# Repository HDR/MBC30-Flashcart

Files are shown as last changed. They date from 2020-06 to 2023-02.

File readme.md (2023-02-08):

## Make sure you read the license, if you see anyone selling these, please send me a message.

MBC30 Flashcart inspired by retroreboot's MBC3 cartridge.

## Ordering

**OSHPark:** 

[Regular Version](https://oshpark.com/shared_projects/xqcPwiVB)

[Crystal Clear Version](https://oshpark.com/shared_projects/qh5Q5MuF)

Make sure to select the "2 oz copper, 0.8mm thickness" option before checkout

**JLCPCB:**

Upload gerbers(.zip files) to [JLCPCB](http://jlcpcb.com)

Make sure you order with the following settings:

PCB Thickness: 0.8

PCB Color: Any

Surface Finish: ENIG-RoHS

Gold Fingers: Yes (45° chamfered border)

Castellated Holes: No

**PCBWay:**

[Regular Version](https://www.pcbway.com/project/shareproject/MBC30_Flashcart___4MB___FRAM___RTC___Suicune_Edition_1.html)

[Crystal Clear Version](https://www.pcbway.com/project/shareproject/MBC30_Flashcart___4MB___FRAM___RTC___Crystal_Clear_Edition_1.html)

[Coral Version](https://www.pcbway.com/project/shareproject/MBC30_Flashcart_4MB_FRAM_RTC_Coral_Edition_2b0fe0be.html)

## BOM

| Reference | Part Number | Description  |
| --- |:---:| -----:|
| B1 | BK-6219-TR | CR2025 Coin Cell Retainer |
| C1, C2, C3, C6, C7 | 06033C104KAT4A | 0.1uF Capacitor |
| C4, C5 | CL10C150JB8NNNC | 15pF Capacitor |
| RAM | FM18W08 | 256kbit FRAM |
| R1 | ERJ-PA3J334V | 330K Ω Resistor |
| R2 | ERJ-PA3J103V | 10K Ω Resistor |
| R3 | ERJ-PA3J102V | 1K Ω Resistor |
| MBC30 | MBC30 | Get from real cartridge |
| U1 | BA6129AF | Buy or get from real cartridge |
| U2 | 74LVC1G332GV,125 | 3-input OR gate TSOP-6 |
| ROM | AM29F032 (4MB) or MBM29F033C (4MB) | 4MB Rom Chip TSOP-40 |
| X1 | R26-32.768-12.5-10PPM | R26 12.5pF 32.768 kHz Crystal |

Note: Capacitors and Resistor part numbers are suggestions, you can use other components with matching specs

On 1.4.1 boards the flash should be soldered the other way around, as the indicator is wrong

## Images

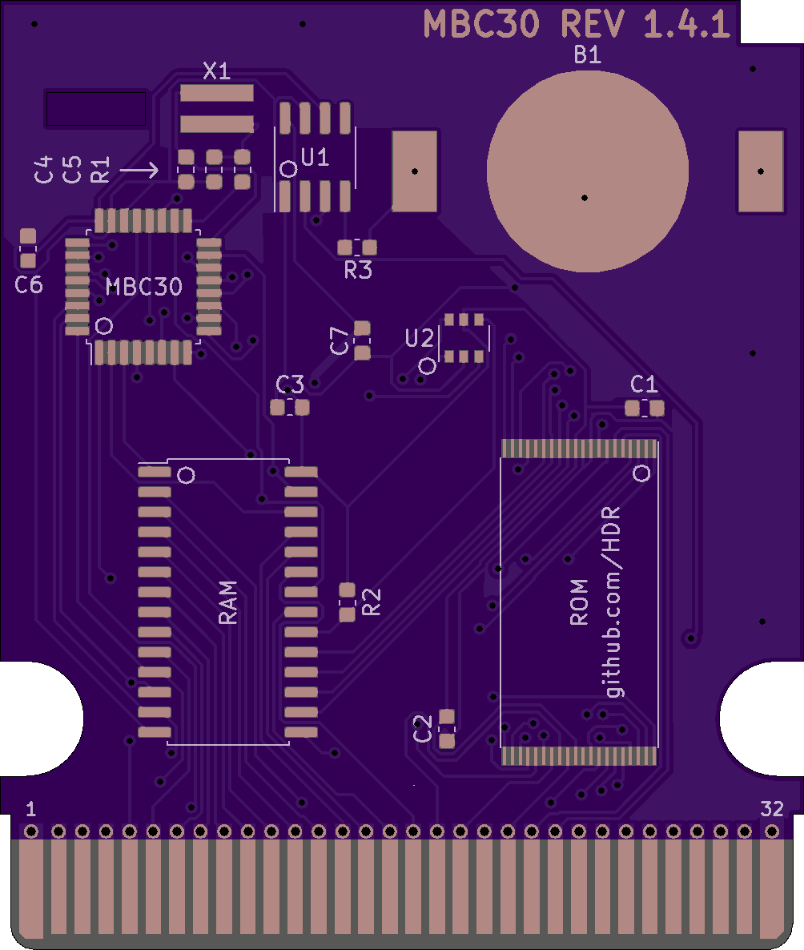
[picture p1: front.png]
Front


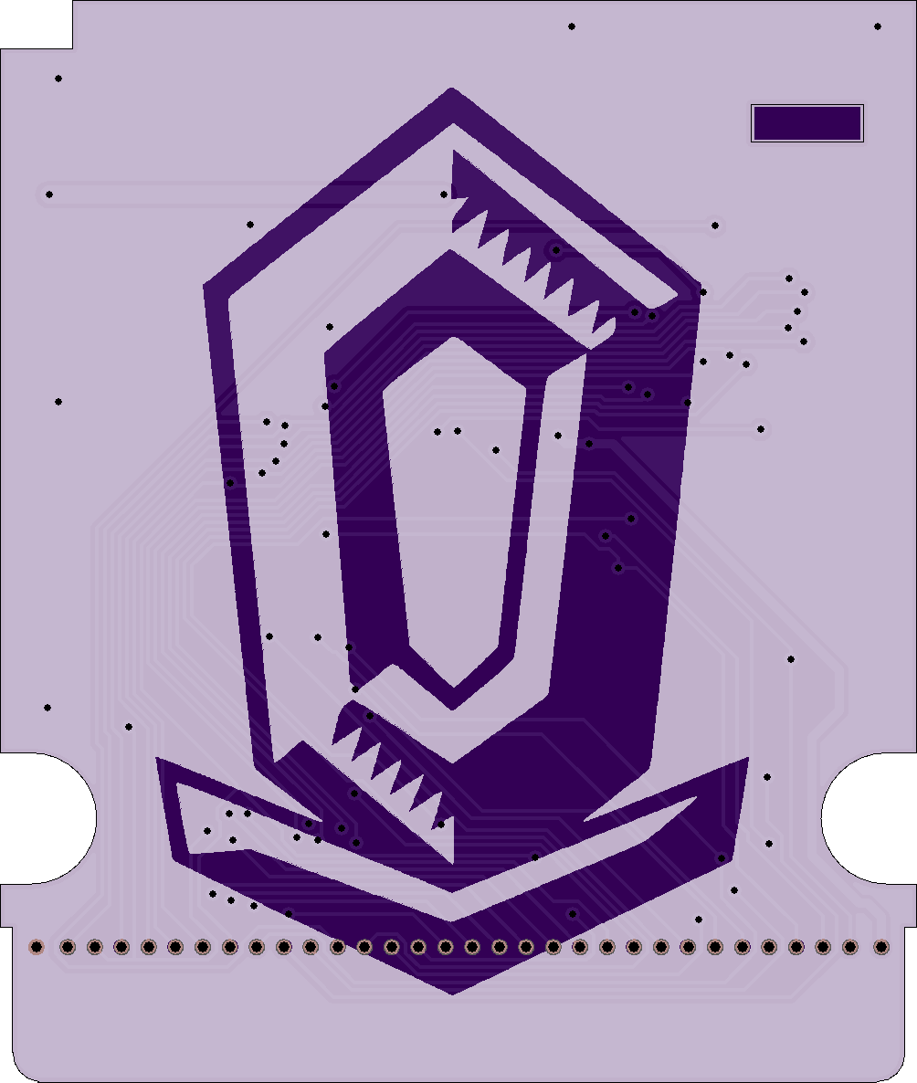
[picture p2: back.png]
Back


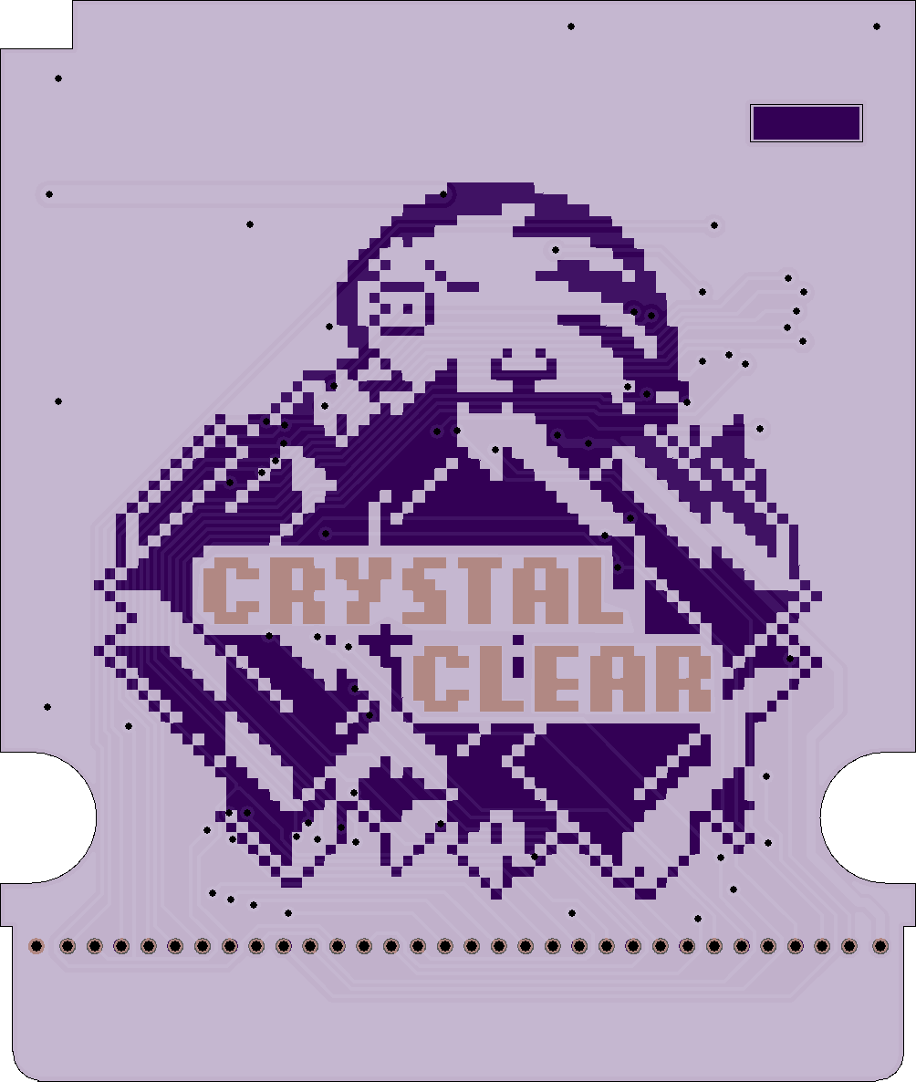
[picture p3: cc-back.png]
CCBack


**Changelog:**

**1.1:**

- Rewired WE on the ROM chip to Pin 31 on the cart bus to fix an issue where it would not write to a bank.

**1.2:**

- Changed the PCB to fit inside Japanese Pokemon Crystal shells
- Added inverted silkscreen to the board to make it look more like the original
- Added Crystal Clear edition

**1.3:**

- The pinout for the MBC30 listed online is wrong, thanks to [Alex](https://github.com/insidegadgets) over at [InsideGadgets](https://shop.insidegadgets.com/) for providing a fixed MBC30 pinout.

- Removed the front silk screens as most manufacturers struggle to make it.

**1.3.1:**

- Moved C2 to make it easier to close the shell

**1.4:**

- Switched cart bus footprint to [djedditt's replica of an original one](https://github.com/djedditt/kicad-gamepaks)

- Replaced the flash chip footprint with a TSOP-40 footprint.

- Redid the ground plane by hand, it should now look much better.

- Moved the battery receptacle footprint 0.5mm to the left.

- Renamed Y1 to X1

- Removed JLCJLCJLC marking for OSHPark project.

**1.4.1:**

- Fixed missing trace for Ram_CS

**1.4.2:**

- Fixed a symbol kicad "rescued" causing the pinout to be backwards (this put the chip direction indicator in the wrong corner)

## Videos

**Makho Building Revision 1.3.1**

text (https://www.youtube.com/watch?v=wJTDsA5XWiE)

**Mizuho Building Revision 1.3**

text (https://www.youtube.com/watch?v=DfoEXSLMXps)

**AndehX Building Revision 1.4.1**

text (https://www.youtube.com/watch?v=C_L1obcNi5A)

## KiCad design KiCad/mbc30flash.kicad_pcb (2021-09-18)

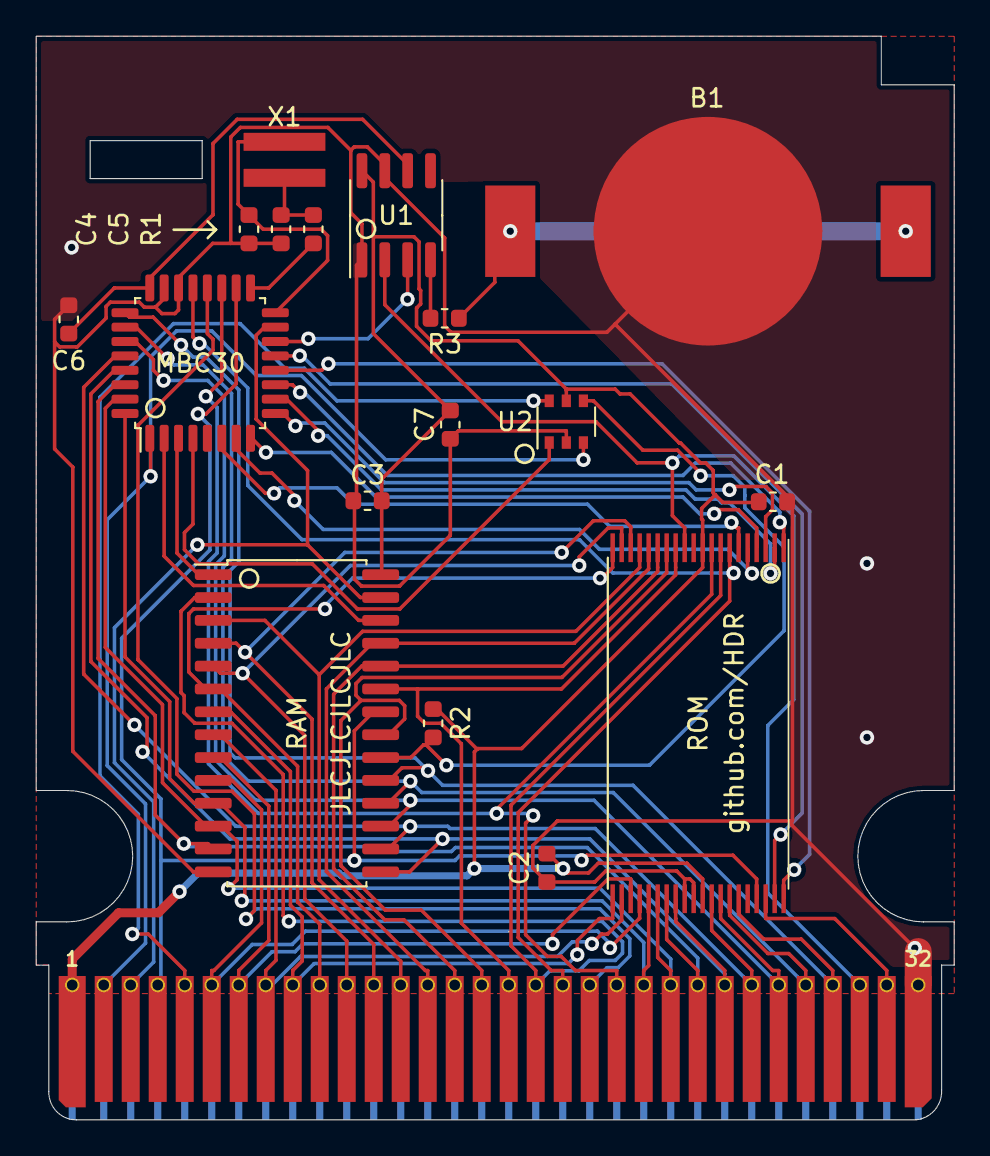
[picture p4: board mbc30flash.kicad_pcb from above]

Board: 2 copper layers, 51.0 x 60.2 mm, 19 parts (1 on the bottom side), 51 nets.

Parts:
Art1: 90,412581|99,90646 | Crystal Clear; Suicune-Back-Silkscreen
B1: Battery_Cell; BK-6219-TR
C1, C2, C3, C6, C7: 0.1 uF; C_0603_1608Metric
C4, C5: 15 pF; C_0603_1608Metric
MBC30: MBC30; LQFP-32_7x7mm_P0.8mm
R1: 330K; R_0603_1608Metric
R2: 10K; R_0603_1608Metric
R3: 1K; R_0603_1608Metric
RAM: FM18W08; SOIC-28W_7.5x17.9mm_P1.27mm
ROM: AM29F032/MBM29F033C; AM29F032-MBM29F033C
U0: CartBus; GameBoy_GamePak_CGB-002_P1.50mm_Edge
U1: BA6129AF; SOIC-8_3.9x4.9mm_P1.27mm
U2: 74LVC1G332GW,125; TSOP-6_1.65x3.05mm_P0.95mm
X1: Crystal; Resonator_SMD_muRata_CDSCB-2pin_4.5x2.0mm_HandSoldering

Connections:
#CE: R2.1, RAM.20, U2.4
A0: RAM.10, ROM.24, U0.6
A1: RAM.9, ROM.23, U0.7
A2: RAM.8, ROM.22, U0.8
A3: RAM.7, ROM.21, U0.9
A4: RAM.6, ROM.20, U0.10
A5: RAM.5, ROM.19, U0.11
A6: RAM.4, ROM.18, U0.12
A7: RAM.3, ROM.17, U0.13
A8: RAM.25, ROM.16, U0.14
A9: RAM.24, ROM.15, U0.15
A10: RAM.21, ROM.14, U0.16
A11: RAM.23, ROM.13, U0.17
A12: RAM.2, ROM.8, U0.18
A13: MBC30.21, ROM.7, U0.19
A14: MBC30.20, U0.20
A15: MBC30.19, ROM.9, U0.21
AA13: MBC30.2, RAM.26
AA14: MBC30.3, RAM.1
CLK: MBC30.1, U0.2, U2.3
CS: U0.5, U2.6
D0: MBC30.32, RAM.11, ROM.25, U0.22
D1: MBC30.31, RAM.12, ROM.26, U0.23
D2: MBC30.30, RAM.13, ROM.27, U0.24
D3: MBC30.29, RAM.15, ROM.28, U0.25
D4: MBC30.28, RAM.16, ROM.32, U0.26
D5: MBC30.27, RAM.17, ROM.33, U0.27
D6: MBC30.26, RAM.18, ROM.34, U0.28
D7: MBC30.25, RAM.19, ROM.35, U0.29
GND: B1.2, C1.1, C2.2, C3.1, C4.2, C5.1, C6.2, C7.1, MBC30.22, MBC30.23, RAM.14, ROM.29, ROM.30, U0.32, U1.1, U1.7, U2.2
unnamed: B1.1, R3.1
unnamed: C5.2, R1.2, X1.1
unnamed: R3.2, U1.4
PWR: C6.1, MBC30.24, U1.6
RA14: MBC30.6, ROM.6
RA15: MBC30.7, ROM.5
RA16: MBC30.8, ROM.4
RA17: MBC30.9, ROM.3
RA18: MBC30.10, ROM.2
RA19: MBC30.11, ROM.1
RA20: MBC30.12, ROM.40
RA21: MBC30.13, ROM.39
RESET: ROM.12, U0.30, U1.2
VCC: C1.2, C2.1, C3.2, C7.2, R2.2, RAM.28, ROM.10, ROM.31, U0.1, U1.8, U2.5
WE_AUDIO: ROM.38, U0.31
XIN: C4.1, MBC30.16, X1.2
XOUT: MBC30.17, R1.1
\RAMCS: MBC30.4, U2.1
\RD: MBC30.18, RAM.22, ROM.37, U0.4
\RST: MBC30.14, U1.3
\WR: MBC30.15, RAM.27, U0.3

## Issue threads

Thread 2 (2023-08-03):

BOM CPL FILE

kazzaluis, 2023-08-03:
Where i can find this files, JLCPCB need it to continue

HDR, 2023-08-03:
These are not intended to be factory assembled, some parts are only available from donor cartridges.

Closed 2023-08-03.

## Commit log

2019-10-24 Rev 1.2
    - Changed the PCB to fit inside Japanese Pokemon Crystal shells
    - Added inverted silkscreen to the board to make it look more like the
    original
    - Added Crystal Clear version of the pcb
2020-05-22 Add kicad files
    Added kicad files for both the Suicune "Regular" version, and the files for the Crystal Clear edition
    [mbc30flash-cc.kicad_pcb, mbc30flash.kicad_pcb, mbc30flash.sch]
2020-05-23 Clean up BOM
2020-06-08 Revision 1.4
    - Switched cart bus footprint to [djedditt's replica of an original one](https://github.com/djedditt/kicad-gamepaks)
    - Replaced the flash chip footprint with a TSOP-40 footprint.
    - Redid the ground plane by hand, it should now look much better.
    - Moved the battery receptacle footprint 0.5mm to the left.
    - Renamed Y1 to X1
    - Removed JLCJLCJLC marking for OSHPark project.
    - Cleaned up schematic, it should now be much more readable.
    [mbc30flash-cc.kicad_pcb, mbc30flash.kicad_pcb, mbc30flash.sch]
2020-06-21 1.4.1
    Fixed missing RAM_CS trace
    [mbc30flash-cc.kicad_pcb, mbc30flash.sch]
2020-06-21 1.4.1
    - Fixed missing trace for Ram_CS
2020-08-25 1.4.2
    - Fixed a symbol kicad "rescued" causing the pinout to be backwards (this put the chip direction indicator in the wrong corner)
    [mbc30flash-cc.kicad_pcb, mbc30flash.kicad_pcb]
2021-09-18 Fix incorrect labels in schematic
    [mbc30flash-cc.kicad_pcb, mbc30flash.kicad_pcb, mbc30flash.sch]
